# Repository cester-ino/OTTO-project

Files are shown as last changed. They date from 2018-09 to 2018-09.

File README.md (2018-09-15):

## OTTO-project
Hardware prototype for the OTTO Synthesizer 

Use Kicad to open the project

prototype rendering

The main features are (for now):

 - **50 key button matrix** 
 - **4 clickable color coded encoders**
 - **1W Audio amplifier** for the internal speaker
 - **Battery management and charging** circuit for the lipo/li-ion batteries and a led battery meter  
 - **Gpio breakout** to allow to position the Raspberry rotated 90 degrees to access the USB ports and to easely use both the LCD screen and the audio card.

prototype rendering

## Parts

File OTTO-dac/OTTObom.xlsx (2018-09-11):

Refs | Value | Footprint | Quantity | MFR | MPN | SPR | SPN | Column1
SW55 | ON_OFF_SWITCH | Button_Switch_THT:SK-12E12-G5 | 1 |  |  | lcsc | C136720
SW8;SW7;SW11;SW12;SW15;SW19;SW23;SW27;SW30;SW34;SW36;SW37;SW39;SW43;SW47;SW50;SW18;SW22;SW26;SW33;SW35;SW38;SW42;SW46;SW3;SW4;SW2;SW1;SW5;SW6;SW10;SW14;SW17;SW9;SW13;SW16;SW49;SW45;SW41;SW40;SW44;SW48;SW31;SW28;SW24;SW29;SW25;SW21;SW20;SW32 | SW_Push | Button_Switch_THT:Tactile_Switch_12x12x7.3_mm | 50 | - | - | lcsc | -
MK1 | Microphone | CMA-4544PF-W:CMA-4544PF-W | 1 | - | - | lcsc | C241681 (https://lcsc.com/product-detail/Others_INGHAi-GMI9750UP-2C44DB_C241681.html)
C22 | 0.01uF | Capacitor_SMD:C_0805_2012Metric | 1 | - | - | lcsc | C83170 (https://lcsc.com/product-detail/Multilayer-Ceramic-Capacitors-MLCC-SMD-SMT_10nF-103-10-50V_C83170.html)
C7;C11;C8;C9;C10;C13;C1;C6;C5;C21 | 0.1uF | Capacitor_SMD:C_0805_2012Metric | 10 | - | - | lcsc | C29926 (https://lcsc.com/product-detail/Multilayer-Ceramic-Capacitors-MLCC-SMD-SMT_100nF-104-5-50V_C29926.html) | V
C24 | 100pF | Capacitor_SMD:C_0805_2012Metric | 1 | - | - | lcsc | C107140 (https://lcsc.com/product-detail/Multilayer-Ceramic-Capacitors-MLCC-SMD-SMT_100pF-101-10-50V_C107140.html)
C12 | 10uF | Capacitor_SMD:C_0805_2012Metric | 1 | - | - | lcsc | C48181 (https://lcsc.com/product-detail/Multilayer-Ceramic-Capacitors-MLCC-SMD-SMT_10uF-106-20-25V_C48181.html)
C2;C23 | 1uF | Capacitor_SMD:C_0805_2012Metric | 2 | - | - | lcsc | C89378 (https://lcsc.com/product-detail/Multilayer-Ceramic-Capacitors-MLCC-SMD-SMT_1uF-105-20-25V_C89378.html)
C3;C4 | 22pF | Capacitor_SMD:C_0805_2012Metric | 2 | - | - | lcsc | C38143 (https://lcsc.com/product-detail/Multilayer-Ceramic-Capacitors-MLCC-SMD-SMT_22pF-220-5-50V_C38143.html)
C14 | 22uF | Capacitor_SMD:C_0805_2012Metric | 1 | - | - | lcsc | C89572 (https://lcsc.com/product-detail/Multilayer-Ceramic-Capacitors-MLCC-SMD-SMT_22uF-226-20-10V_C89572.html)
C19;C20 | 0.1uf | Capacitor_Tantalum_SMD:CP_EIA-2012-12_Kemet-R | 2 | - | - | lcsc | C154088
C18 | 1uf | Capacitor_Tantalum_SMD:CP_EIA-2012-12_Kemet-R | 1 | - | - | lcsc | C116269 (https://lcsc.com/product-detail/Tantalum-Capacitors_KEMET_T491A105K016AT_1uF-105-10-16V_C116269.html)
C16;C17 | 220uf | Capacitor_Tantalum_SMD:CP_EIA-2012-12_Kemet-R | 2 | - | - | lcsc | C7200
C15 | 22uF | Capacitor_Tantalum_SMD:CP_EIA-2012-12_Kemet-R | 1 | - | - | lcsc | C117031 (https://lcsc.com/product-detail/Tantalum-Capacitors_KEMET_T491B226M010AT_22uF-226-20-10V_C117031.html)
J10 | Conn_01x04_Male | Connector_JST:JST_SH_SM04B-SRSS-TB_1x04-1MP_P1.00mm_Horizontal | 1 | - | - | lcsc | C160404
J6 | Speaker | Connector_JST:JST_XH_B02B-XH-A_1x02_P2.50mm_Vertical | 1 | JST | XH-B02B | lcsc | C20079 (https://lcsc.com/product-detail/XH-Connectors_XH-2A-2P-pitch2-5mm-Straight-line_C20079.html)
J3 | battery | Connector_JST:JST_XH_B02B-XH-A_1x02_P2.50mm_Vertical | 1 | JST | XH-B02B | lcsc | C20079 (https://lcsc.com/product-detail/XH-Connectors_XH-2A-2P-pitch2-5mm-Straight-line_C20079.html)
J1 | USB | Connector_PinHeader_2.54mm:PinHeader_1x04_P2.54mm_Vertical | 1 | - | 1x04 pin header | lcsc | C124378 (https://lcsc.com/product-detail/Male-Header_Shenzhen-Cancome-Headers-Pins-1-4P-2-54mm-Straight-line_C124378.html)
J4 | audio | Connector_PinHeader_2.54mm:PinHeader_1x04_P2.54mm_Vertical | 1 | - | 1x04 pin header | lcsc | C124378 (https://lcsc.com/product-detail/Male-Header_Shenzhen-Cancome-Headers-Pins-1-4P-2-54mm-Straight-line_C124378.html)
J8 | gpio_exp1 | Connector_PinHeader_2.54mm:PinHeader_2x20_P2.54mm_Vertical | 1 | 2x20 long pin header | - | lcsc | C124383 (https://lcsc.com/product-detail/Male-Header_Shenzhen-Cancome-Headers-Pins-2-20P-2-54mm-Straight-line_C124383.html)
J7 | gpio_exp2 | Connector_PinHeader_2.54mm:PinHeader_2x20_P2.54mm_Vertical | 1 | 2x20 pin header | - | lcsc | C124383 (https://lcsc.com/product-detail/Male-Header_Shenzhen-Cancome-Headers-Pins-2-20P-2-54mm-Straight-line_C124383.html)
J2 | USB_B_Micro | Connector_USB:USB_Micro-B_Molex-105017-0001 | 1 | Molex | 105017-0001 | lcsc | C136000 (https://lcsc.com/product-detail/Micro-USB-Connectors_MOLEX_105017-0001_105017-0001_C136000.html)
Y1 | 16mhz | Crystal:Crystal_SMD_Abracon_ABM3-2Pin_5.0x3.2mm | 1 | - | ABM3-16.000MHZ-D2Y-T | lcsc | C112572 (https://lcsc.com/product-detail/SMD-Crystals_YSX530GA-16MHZ-20PF-10PPM-40-85_C112572.html)
D58 | SS34 | Diode_SMD:D_SMC | 1 | - | SS34 | lcsc | C13763 (https://lcsc.com/product-detail/Schottky-Barrier-Diodes-SBD_Jiangsu-Yutai-Elec-SS34_C13763.html)
D9;D8;D12;D13;D16;D20;D24;D28;D31;D35;D37;D38;D40;D44;D48;D51;D19;D23;D27;D34;D36;D39;D43;D47;D4;D5;D3;D2;D6;D7;D11;D15;D18;D10;D14;D17;D50;D46;D42;D41;D45;D49;D32;D29;D25;D30;D26;D22;D21;D33;D52;D53;D54;D55 | 1N4148 | Diode_SMD:D_SOD-123v | 54 | - | 1N4148W-E3-18 | lcsc | C129216 (https://lcsc.com/product-detail/Switching-Diode_1N4148W_C129216.html)
U7 | TJCTM24028-SPI | Display:TJCTM24028-SPI | 1 | - | - | lcsc | -
L1 | 22uH | Inductor_SMD:L_7.3x7.3_H4.5 | 1 | Epcos |  | lcsc | C181754
D1 | LED | LED_SMD:LED_0805_2012Metric | 1 | - | HSMW-C170-U0000 | lcsc | C34499 (https://lcsc.com/product-detail/Light-Emitting-Diodes-LED_white-0805_C34499.html)
D57 | LEDG | LED_SMD:LED_0805_2012Metric | 1 | - | HSMQ-C170-T0000 | lcsc | C74344 (https://lcsc.com/product-detail/Light-Emitting-Diodes-LED_0805_C74344.html)
D56 | LEDR | LED_SMD:LED_0805_2012Metric | 1 | - | HSMC-C170-T0000 | lcsc | C131250 (https://lcsc.com/product-detail/Infrared-IR-LEDs_Everlight-Elec-IR17-21C-TR8_C131250.html)
D59;D60;D61;D62;D63 | LED | LED_SMD:LED_0805_2012Metric | 5 | - | HSMW-C170-U0000 | lcsc | C34499 (https://lcsc.com/product-detail/Light-Emitting-Diodes-LED_white-0805_C34499.html)
IC2 | LM3914 | Package_LCC:PLCC-20 | 1 | - | LM3914VX/NOPB | lcsc | C9408 (https://lcsc.com/product-detail/LED-Drivers_TI_LM3914N-1-NOPB_LM3914N-1-NOPB_C9408.html)
U1 | ATMEGA32U4-AU | Package_QFP:TQFP-44-1EP_10x10mm_P0.8mm_EP4.5x4.5mm | 1 | - | ATMEGA32U4-AU | lcsc | 556-ATMEGA32U4-AU
IC1 | 74HC125 | Package_SO:SOIC-14_3.9x8.7mm_P1.27mm | 1 | - | SN74HC125DR | lcsc | 595-SN74HC125DR
U6 | LM4860 | Package_SO:SOIC-16_3.9x9.9mm_P1.27mm | 1 | - | LM4860MX/NOPB | lcsc | -
U2 | MCP602 | Package_SO:SOIC-8_3.9x4.9mm_P1.27mm | 1 | - | MCP6022T-I/SN | lcsc | -
U3 | TP4056 | Package_SO:Texas_HTSOP-8-1EP_3.9x4.9mm_P1.27mm_EP2.95x4.9mm_Mask2.4x3.1mm_ThermalVias | 1 | - | TP4056 SOP-8 | lcsc | C16581 (https://lcsc.com/product-detail/PMIC-Battery-Management_TP4056_C16581.html)
U4 | FS312F-G | Package_TO_SOT_SMD:SOT-23-6 | 1 | - | FS312F-G SOT-23 | lcsc | C82736 (https://lcsc.com/product-detail/Battery-Protection-ICs_FS312F-G_C82736.html)
U5 | MT3608 | Package_TO_SOT_SMD:SOT-23-6 | 1 | - | MT3608 SOT-23 | lcsc | C84817 (https://lcsc.com/product-detail/DC-DC-Converters_MT3608_C84817.html)
M1 | FS8205 | Package_TO_SOT_SMD:SOT-23-6_Handsoldering | 1 | - | FS8205 SOT-23 | lcsc | C94488 (https://lcsc.com/product-detail/MOSFET_RU8205C6_C94488.html)
U8 | MAX4466 | Package_TO_SOT_SMD:SOT-353_SC-70-5 | 1 | - | - | lcsc | -
Q1 | 2N7000 | Package_TO_SOT_THT:TO-92_Inline | 1 | - | - | lcsc | C232838
RV1 | 10K | Potentiometer_SMD:Potentiometer_Vishay_TS53YJ_Vertical | 1 | - | TS53YJ103MR10 | lcsc | C118956 (https://lcsc.com/product-detail/Precision-Potentiometer_10KR_C118956.html)
R15;R13 | 1.5K | Resistor_SMD:R_0805_2012Metric | 2 | - | - | lcsc | C114737 (https://lcsc.com/product-detail/Chip-Resistor-Surface-Mount_1-5KR-152-5_C114737.html) | V
R23;R31;R32;R35;R41 | 100K | Resistor_SMD:R_0805_2012Metric | 5 | - | - | lcsc | C96346 (https://lcsc.com/product-detail/Chip-Resistor-Surface-Mount_100KR-1003-1_C96346.html) | V
R1;R8;R3;R12;R7;R9;R4;R10;R5;R11;R6;R33;R34 | 10K | Resistor_SMD:R_0805_2012Metric | 13 | - | - | lcsc | C101926 (https://lcsc.com/product-detail/Chip-Resistor-Surface-Mount_10KR-103-5_C101926.html) | V
R18 | 15K | Resistor_SMD:R_0805_2012Metric | 1 | - | - | lcsc | C114559 (https://lcsc.com/product-detail/Chip-Resistor-Surface-Mount_15KR-1502-1_C114559.html) | V
R17;R19;R21;R20;R26;R30;R29;R28;R40;R38;R36 | 1K | Resistor_SMD:R_0805_2012Metric | 11 | - | - | lcsc | C100046 (https://lcsc.com/product-detail/Chip-Resistor-Surface-Mount_1KR-102-5_C100046.html) | V
R39;R37 | 1M | Resistor_SMD:R_0805_2012Metric | 2 | - | - | lcsc | C107700 (https://lcsc.com/product-detail/Chip-Resistor-Surface-Mount_1MR-1004-1_C107700.html) | V
R24 | 2.7k | Resistor_SMD:R_0805_2012Metric | 1 | - | - | lcsc | C137454 | V
R22 | 2k | Resistor_SMD:R_0805_2012Metric | 1 | - | - | lcsc | C114748 (https://lcsc.com/product-detail/Chip-Resistor-Surface-Mount_2KR-202-5_C114748.html) | V
R2 | 330K | Resistor_SMD:R_0805_2012Metric | 1 | - | - | lcsc | C114528 (https://lcsc.com/product-detail/Chip-Resistor-Surface-Mount_330KR-3303-1_C114528.html) | V
R27 | 4.7K | Resistor_SMD:R_0805_2012Metric | 1 | - | - | lcsc | C60816 (https://lcsc.com/product-detail/Chip-Resistor-Surface-Mount_4-7K-4701-1_C60816.html) | V
R14 | 470K | Resistor_SMD:R_0805_2012Metric | 1 | - | - | lcsc | C104346 (https://lcsc.com/product-detail/Chip-Resistor-Surface-Mount_470KR-4703-1_C104346.html) | V
R25 | 7.5K | Resistor_SMD:R_0805_2012Metric | 1 | - | - | lcsc | C114547 (https://lcsc.com/product-detail/Chip-Resistor-Surface-Mount_7-5KR-7501-1_C114547.html) | V
R16 | 820K | Resistor_SMD:R_0805_2012Metric | 1 | - | - | lcsc | C141700 | V
SW51;SW52;SW53;SW54 | Rotary_Encoder_Switch | Rotary_Encoder:RotaryEncoder_Alps_EC12E-Switch_Vertical_H20mm_CircularMountingHoles | 4 | - |  | lcsc | C202365
J5 | SJ1-42536-SMT | SJ1:CUI_SJ1-42536-SMT | 1 | Cui | SJ1-42536-SMT | lcsc | C128992

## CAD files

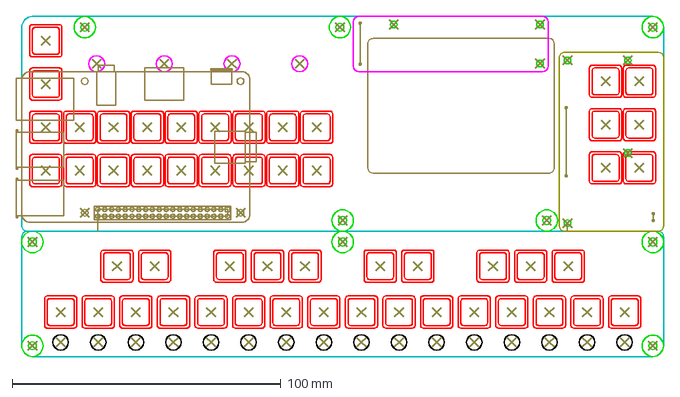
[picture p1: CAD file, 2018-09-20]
OTTO_align.dxf
241.0 x 126.6 mm

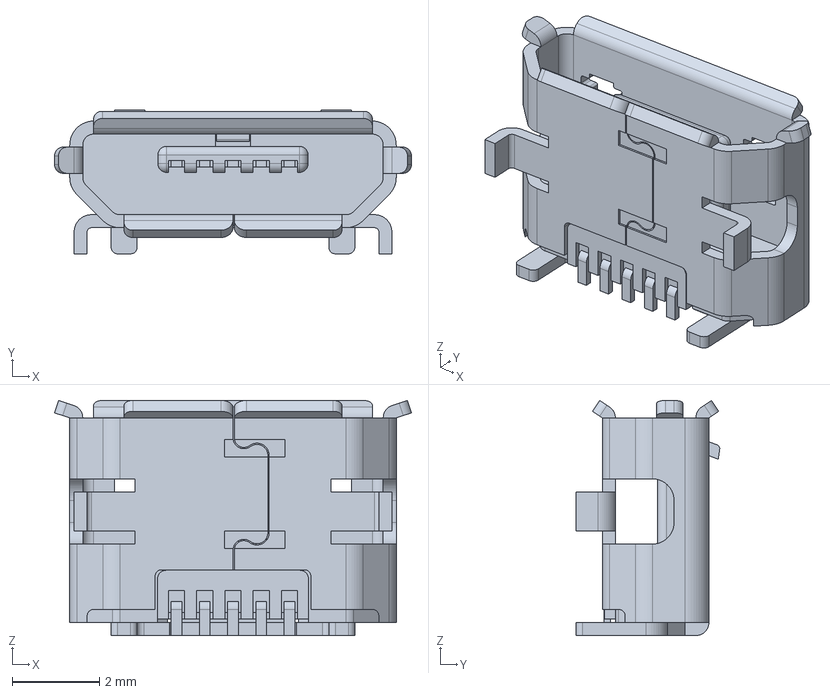
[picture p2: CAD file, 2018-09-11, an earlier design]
OTTO-old/3D Shapes/1050170001.stp
8.20 x 3.30 x 5.40 mm

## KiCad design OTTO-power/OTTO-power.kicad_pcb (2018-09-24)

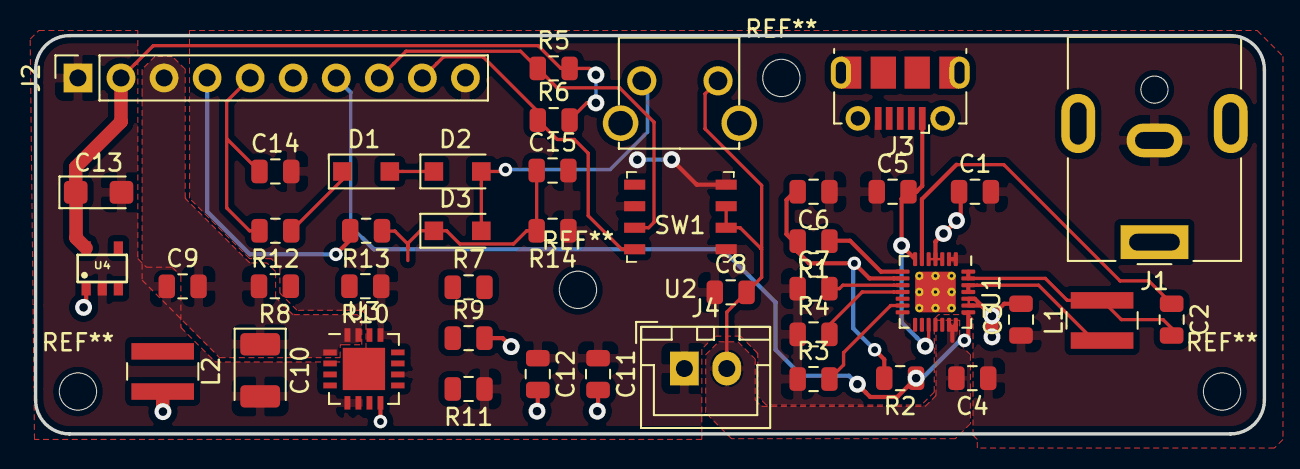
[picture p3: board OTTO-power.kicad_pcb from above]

Board: 2 copper layers, 72.5 x 23.5 mm, 43 parts (0 on the bottom side), 27 nets.

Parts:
C1, C6, C9: 2.2uf; C_0805_2012Metric
C2: 1uf; C_0805_2012Metric
C3, C4, C11: 10uf; C_0805_2012Metric
C5: 4.7uf; C_0805_2012Metric
C7: 0.15uf; C_0805_2012Metric
C8, C12: 0.1uf; C_0805_2012Metric
C10: 100uf; CP_EIA-3528-21_Kemet-B
C13: 10uf; CP_EIA-3216-18_Kemet-A
C14, C15: 0.1uF; C_0805_2012Metric
D1, D2, D3: IN4001; D_SOD-123F
J1: Barrel_Jack; BarrelJack_CUI_PJ-063AH_Horizontal
J2: Conn_01x10; PinSocket_1x10_P2.54mm_Vertical
J3: USB_B_Micro; USB_Micro-B_Molex-105017-0001
J4: battery; JST_XH_B02B-XH-A_1x02_P2.50mm_Vertical
L1: 3.3uH; L_Wuerth_MAPI-4020
L2: 6.8uH; L_Wuerth_MAPI-4020
R1, R2, R5, R6: 100K; R_0805_2012Metric
R3: 1.2K; R_0805_2012Metric
R4: 3K; R_0805_2012Metric
R7, R10: 200K; R_0805_2012Metric
R8, R9: 1.87M; R_0805_2012Metric
R11: 340K; R_0805_2012Metric
R12, R13, R14: 10K; R_0805_2012Metric
SW1: SW_Push; SKHHLVA010
U1: MAX8903A; QFN-28-1EP_4x4mm_P0.4mm_EP2.4x2.4mm_ThermalVias
U2: MAX17048; TDFN-8-1EP
U3: TPS61090; QFN-16-1EP_4x4mm_P0.65mm_EP2.5x2.5mm
U4: XC6210; SOT25

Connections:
3V3: C13.1, J2.2, R5.2, R6.2, U4.5
5V: C9.2, C10.1, J2.3, R8.2, U3.1, U3.15, U3.16
BATT+: C4.2, C8.2, J4.2, R7.2, SW1.1, U1.20, U1.21, U2.2, U2.3
CHG_OUT: J2.7, R2.1, U1.22
DC: C1.1, J1.1, U1.3, U1.4, U1.5
DOK_OUT: J2.6, R1.1, U1.8
EN_PI: C15.1, D3.1, R7.1, R13.1, R14.2, U3.11, U4.3
GNDA: C1.2, C3.1, C4.1, C5.1, C6.1, C7.1, C8.1, C9.1, C10.2, C11.1, C12.1, C13.2, C14.2, C15.2, J1.2, J2.1, J2.10, J3.5, J4.1, R3.1, R4.1, R10.1, R11.1, R14.1, U1.1, U1.2, U1.12, U1.14, U1.15, U1.16, U2.1, U2.4, U2.6, U3.5, U3.6, U3.7, U3.10, U3.13, U3.17, U4.2
unnamed: C2.1, U1.6
unnamed: C2.2, L1.2, U1.27, U1.28
unnamed: C7.2, U1.10
unnamed: D1.1, R12.1
unnamed: D1.2, D2.1
unnamed: D2.2, D3.2, SW1.2
unnamed: L1.1, U1.25, U1.26
unnamed: L2.1, U3.3, U3.4
unnamed: R3.2, U1.13
unnamed: R4.2, U1.11
unnamed: R8.1, R10.2, U3.14
unnamed: R9.1, R11.2, U3.9
OUT_PIN: J2.4, R13.2
SCL: J2.8, R5.1, U2.7
SDA: J2.9, R6.1, U2.8
SENSE_PIN: C14.1, J2.5, R12.2
SYS: C3.2, C11.2, C12.2, L2.2, R9.2, U1.23, U1.24, U3.8, U4.1
USB: C5.2, J3.1, U1.7, U1.17
VL: C6.2, R1.2, R2.2, U1.9

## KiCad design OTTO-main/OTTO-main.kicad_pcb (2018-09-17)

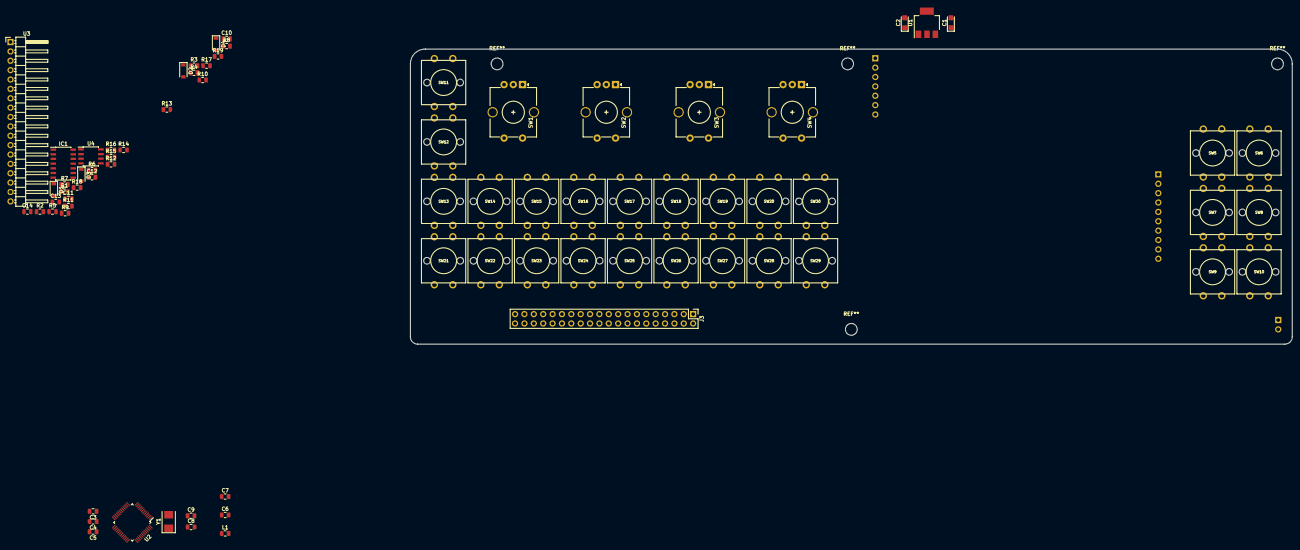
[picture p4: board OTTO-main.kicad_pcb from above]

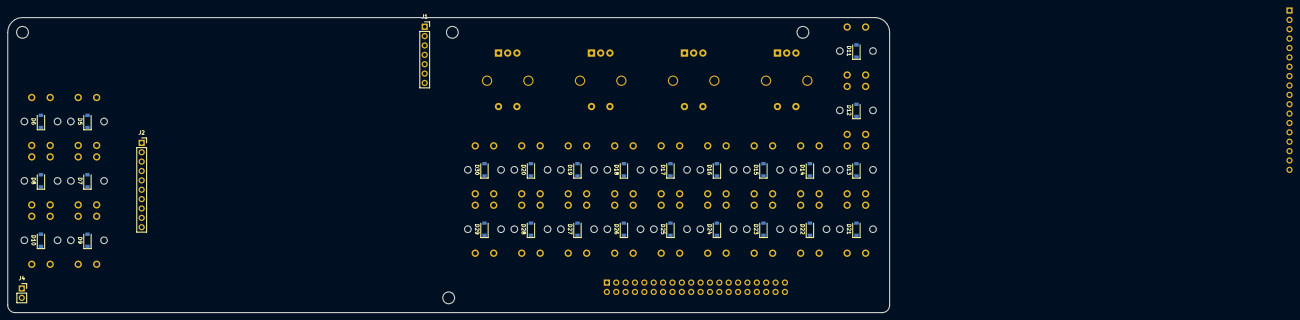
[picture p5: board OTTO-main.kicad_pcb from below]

Board: 2 copper layers, 239.0 x 80.0 mm, 104 parts (29 on the bottom side), 81 nets, no tracks yet.

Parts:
C1: 10uf; CP_EIA-3216-18_Kemet-A
C2: 22uf; CP_EIA-3216-18_Kemet-A
C3, C4, C5, C6: 1uf; C_0805_2012Metric
C7: 10nf; C_0805_2012Metric
C8, C9: 22pf; C_0805_2012Metric
C10, C11, C12, C13, C14: 0.1uF; C_0805_2012Metric
D1, D2, D3, D4: 1N4148; D_SOD-123v
D5, D6, D7, D8, D9, D10, D11, D12, D13, D14, D15, D16, D17, D18, D19, D20, D21, D22, D23, D24, D25, D26, D27, D28, D29, D30: D_ALT; D_SOD-123
IC1: 74HC125; SOIC-14_3.9x8.7mm_P1.27mm
J1: POWER_BOARD; PinSocket_1x07_P2.54mm_Vertical
J2: AUDIO_BOARD; PinSocket_1x10_P2.54mm_Vertical
J3: Raspberry_Pi_2_3; PinHeader_2x20_P2.54mm_Vertical
J4: MICROPHONE; PinSocket_1x02_P2.54mm_Vertical
L1: 30ohm; C_0805_2012Metric
R1, R2: 4.7K; R_0805_2012Metric
R3, R4, R5, R6, R7, R8, R9, R10, R11, R12: 10K; R_0805_2012Metric
R13, R15: 1.5K; R_0805_2012Metric
R14: 470K; R_0805_2012Metric
R16: 820K; R_0805_2012Metric
R17, R19: 1K; R_0805_2012Metric
R18: 15K; R_0805_2012Metric
SW1, SW2, SW3, SW4: Rotary_Encoder_Switch; RotaryEncoder_Alps_EC12E-Switch_Vertical_H20mm_CircularMoun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
SW5, SW6, SW7, SW8, SW9, SW10, SW11, SW12, SW13, SW14, SW15, SW16, SW17, SW18, SW19, SW20, SW21, SW22, SW23, SW24, SW25, SW26, SW27, SW28, SW29, SW30: SW_SPST; Tactile_Switch_12x12x7.3_mm
U1: AMS1117-3.3; SOT-223-3_TabPin2
U2: STM32F103CBTx; LQFP-48_7x7mm_P0.5mm
U3: ILI9341; PinHeader_1x18_P2.54mm_Horizontal
U4: MCP602; SOIC-8_3.9x4.9mm_P1.27mm
Y1: 8mhz; Crystal_SMD_5032-2Pin_5.0x3.2mm

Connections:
5V: J1.2, J2.8
+3V3: C2.1, C3.1, C4.1, C5.1, L1.2, U1.2, U2.24, U2.36, U2.48
+5V: C1.1, IC1.2, IC1.5, IC1.9, IC1.12, IC1.14, R1.2, R2.1, R3.2, R4.2, R5.2, R6.2, R7.2, R18.2, U1.3
A_PIN: IC1.10, R13.2, R14.1, U4.2
BCLK: J2.3, J3.12
CE0: J3.24, U3.5
COL1: D1.1, D11.1, D21.1
COL2: D2.1, D12.1, D22.1
COL3: D3.1, D13.1, D23.1
COL4: D4.1, D14.1, D24.1
COL5: D5.1, D15.1, D25.1
COL6: D6.1, D16.1, D26.1
COL7: D7.1, D17.1, D27.1
COL8: D8.1, D18.1, D28.1
COL9: D9.1, D19.1, D29.1
COL10: D10.1, D20.1, D30.1
D_PIN: C10.1, R8.1
GNDREF: C1.2, C2.2, C3.2, C4.2, C5.2, C6.2, C7.2, C8.2, C9.2, C10.2, C11.2, C12.2, C13.2, C14.2, IC1.7, J2.1, J2.9, J3.6, J3.9, J3.14, J3.20, J3.25, J3.30, J3.34, J3.39, R13.1, R17.2, R19.1, SW1.C, SW2.C, SW3.C, SW4.C, U1.1, U2.44, U3.1, U3.8, U3.11, U3.12, U3.13, U3.14
I2S_RX: J2.4, J3.40
I2S_TX: J2.5, J3.38
INT_PIN: R19.2, U4.1
LED_G: J1.6, J3.18
LED_R: J1.7, J3.22
LR_CLK: J2.2, J3.35
MISO_0: J3.21, U3.7
MOSI_0: J3.19, U3.6
unnamed: C6.1, C7.1, L1.1, U2.9
unnamed: C11.1, IC1.8, R9.1
unnamed: C12.1, IC1.11, R10.1
unnamed: C13.1, IC1.3, R11.1
unnamed: C14.1, IC1.6, R12.1
unnamed: D1.2, SW1.S2
unnamed: D2.2, SW2.S2
unnamed: D3.2, SW3.S2
unnamed: D4.2, SW4.S2
unnamed: D5.2, SW5.2
unnamed: D6.2, SW6.2
unnamed: D7.2, SW7.2
unnamed: D8.2, SW8.2
unnamed: D9.2, SW9.2
unnamed: D10.2, SW10.2
unnamed: D11.2, SW11.2
unnamed: D12.2, SW12.2
unnamed: D13.2, SW13.2
unnamed: D14.2, SW14.2
unnamed: D15.2, SW15.2
unnamed: D16.2, SW16.2
unnamed: D17.2, SW17.2
unnamed: D18.2, SW18.2
unnamed: D19.2, SW19.2
unnamed: D20.2, SW20.2
unnamed: D21.2, SW21.2
unnamed: D22.2, SW22.2
unnamed: D23.2, SW23.2
unnamed: D24.2, SW24.2
unnamed: D25.2, SW25.2
unnamed: D26.2, SW26.2
unnamed: D27.2, SW27.2
unnamed: D28.2, SW28.2
unnamed: D29.2, SW29.2
unnamed: D30.2, SW30.2
unnamed: IC1.1, R15.2, R16.2
unnamed: IC1.4, R15.1
unnamed: IC1.13, R14.2, R16.1
unnamed: R3.1, R8.2, SW1.A, SW2.A, SW3.A, SW4.A
unnamed: R4.1, R9.2, SW1.B
unnamed: R5.1, R10.2, SW2.B
unnamed: R6.1, R11.2, SW3.B
unnamed: R7.1, R12.2, SW4.B
unnamed: R17.1, R18.1, U4.3
OSC_IN: C8.1, U2.5, Y1.1
OSC_OUT: C9.1, U2.6, Y1.2
OUT_PIN: J1.4, J3.15
ROW1: SW1.S1, SW2.S1, SW3.S1, SW4.S1, SW5.1, SW6.1, SW7.1, SW8.1, SW9.1, SW10.1
ROW2: SW11.1, SW12.1, SW13.1, SW14.1, SW15.1, SW16.1, SW17.1, SW18.1, SW19.1, SW20.1
ROW3: SW21.1, SW22.1, SW23.1, SW24.1, SW25.1, SW26.1, SW27.1, SW28.1, SW29.1, SW30.1
SCL: J2.6, J2.7, J3.3, J3.5, R1.1, R2.2, U2.42, U2.43
SCLK_0: J3.23, U3.3
SENSE_PIN: J1.5, J3.16
UART_RXD: J3.10, U2.30
UART_TXD: J3.8, U2.31

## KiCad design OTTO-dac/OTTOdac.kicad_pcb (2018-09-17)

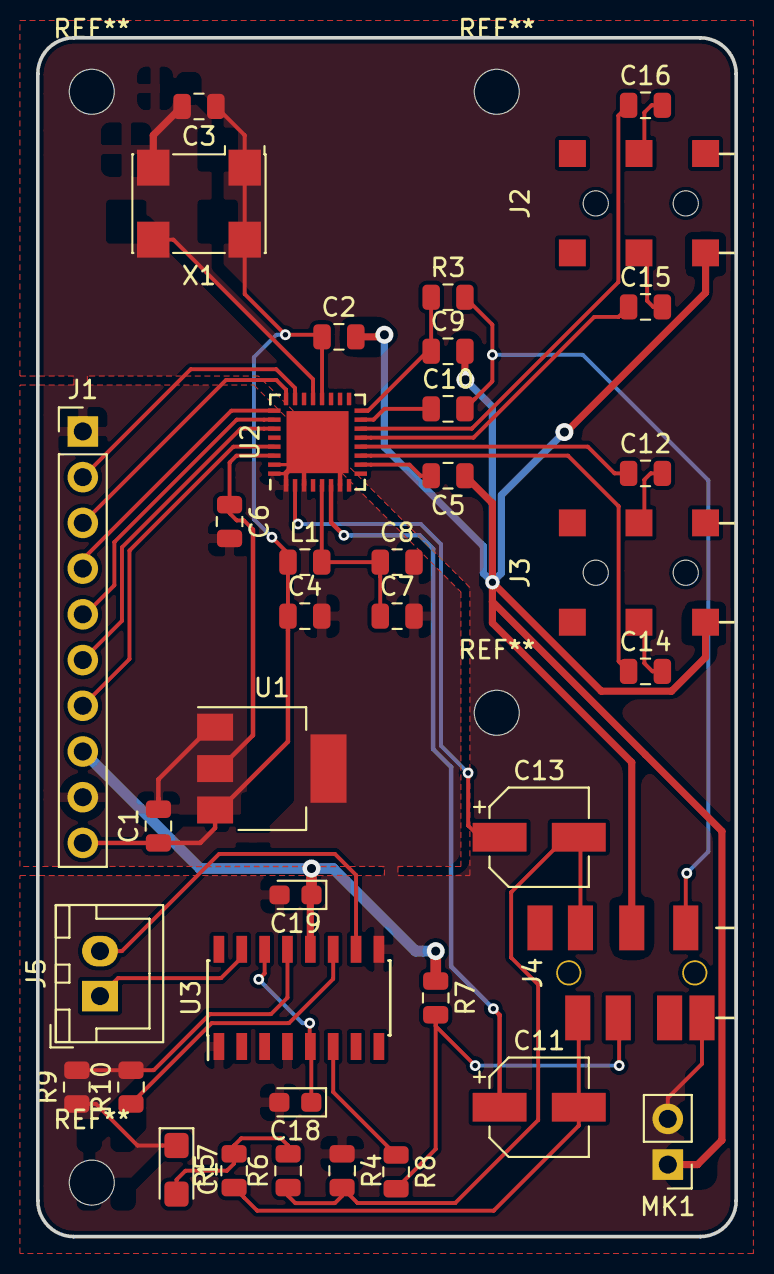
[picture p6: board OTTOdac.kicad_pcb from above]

Board: 2 copper layers, 38.8 x 66.6 mm, 38 parts (0 on the bottom side), 39 nets.

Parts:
C1, C6, C7, C9, C12, C14, C15, C16: 2.2uf; C_0805_2012Metric
C2, C3, C4, C5, C8, C10: 0.1uf; C_0805_2012Metric
C11, C13: 220uf; CP_Elec_5x4.5
C17: 1uf; CP_EIA-3216-18_Kemet-A
C18, C19: 0.1uf; CP_EIA-2012-12_Kemet-R
J1: Conn_01x10; PinHeader_1x10_P2.54mm_Vertical
J2: Audio_IN; PJ-237-6A
J3: Audio_OUT; PJ-237-6A
J4: SJ1-42536-SMT; PJ-393-7A
J5: Speaker; JST_XH_B02B-XH-A_1x02_P2.50mm_Vertical
L1: 600; Fuse_0805_2012Metric
MK1: Microphone; PinHeader_1x02_P2.54mm_Vertical
R3: 2.2K; R_0805_2012Metric
R4, R5, R6: 1K; R_0805_2012Metric
R7, R8: 100K; R_0805_2012Metric
R9, R10: 10K; R_0805_2012Metric
U1: AMS1117-3.3; SOT-223-3_TabPin2
U2: SGTL5000; QFN-32-NXP-SGTL5000
U3: LM4860; SOIC-16_3.9x9.9mm_P1.27mm
X1: XO32; Oscillator_SMD_Abracon_ASV-4Pin_7.0x5.1mm

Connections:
+3V3: C1.1, C2.1, C3.1, C4.1, J1.10, L1.1, U1.3, U2.20, X1.1, X1.4
+5V: C19.1, J1.8, R7.1, U3.12
GNDREF: C1.2, C2.2, C3.2, C4.2, C5.1, C6.2, C7.2, C8.2, C9.2, C18.2, C19.2, J1.1, J1.9, J2.1, J3.1, J4.4, MK1.1, R4.1, U1.1, U2.1, U2.3, U2.7, U2.31, U2.32, U2.33, U3.1, U3.4, U3.9, X1.2
HPL: C11.2, J4.2, R5.1
HPR: C13.2, J4.3, R4.2, R6.1
MIC: C10.2, J4.1, R3.2
unnamed: C5.2, U2.10
unnamed: C6.1, U1.2, U2.30
unnamed: C7.1, C8.1, L1.2, U2.5
unnamed: C9.1, R3.1, U2.16
unnamed: C10.1, U2.15
unnamed: C11.1, U2.6
unnamed: C12.1, U2.12
unnamed: C12.2, J3.2
unnamed: C13.1, U2.2
unnamed: C14.1, U2.11
unnamed: C14.2, J3.3
unnamed: C15.1, U2.13
unnamed: C15.2, J2.3
unnamed: C16.1, U2.14
unnamed: C16.2, J2.2
unnamed: C17.1, R9.1
unnamed: C17.2, R5.2, R6.2
unnamed: C18.1, U3.5, U3.14
unnamed: J4.6, R7.2, R8.2
unnamed: J4.8, MK1.2
unnamed: J5.1, U3.15
unnamed: J5.2, U3.10
unnamed: R8.1, U3.6
unnamed: R10.1, U3.11
unnamed: R9.2, R10.2, U3.13
unnamed: U2.21, X1.3
unnamed: U3.2, U3.3
PIN3: J1.6, U2.27
PIN5: J1.7, U2.29
PIN12: J1.3, U2.24
PIN35: J1.2, U2.23
PIN38: J1.5, U2.26
PIN40: J1.4, U2.25

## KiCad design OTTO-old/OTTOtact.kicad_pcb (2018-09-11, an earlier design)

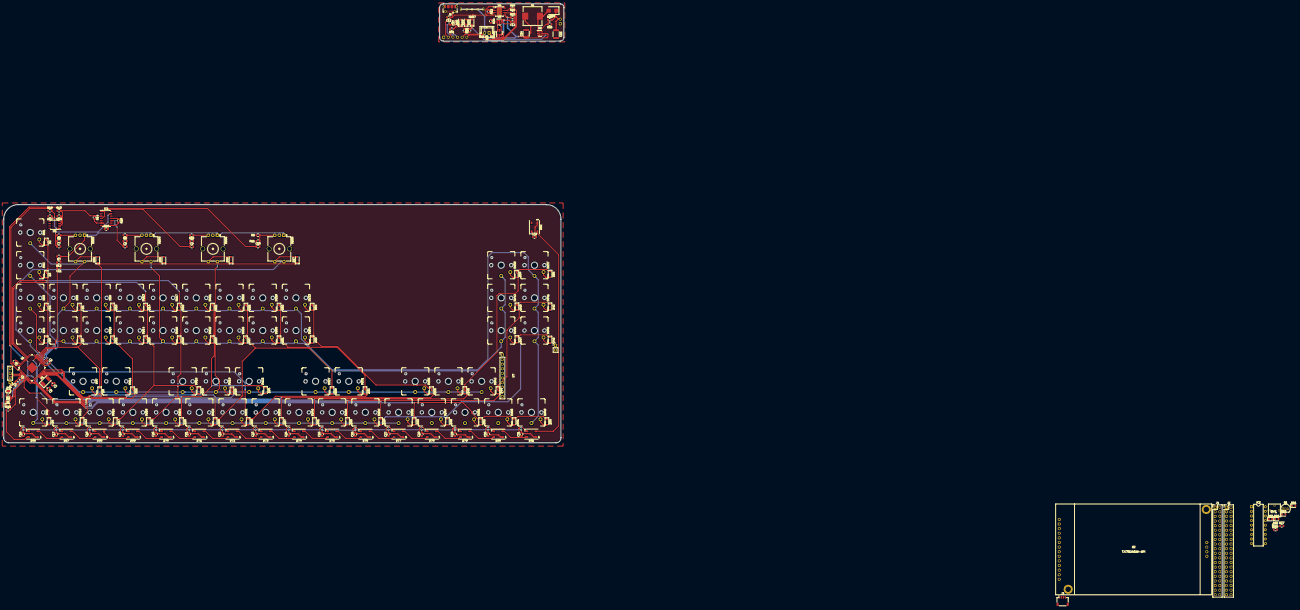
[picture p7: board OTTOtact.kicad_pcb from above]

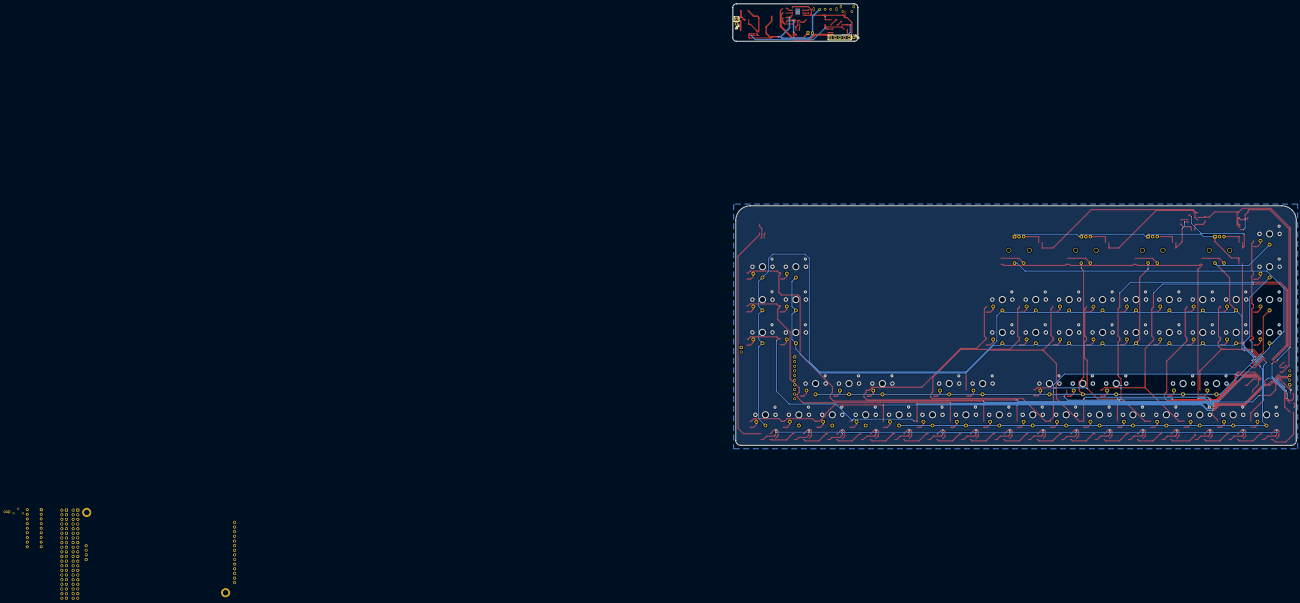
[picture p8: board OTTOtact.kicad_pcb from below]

Board: 2 copper layers, 307.0 x 131.2 mm, 229 parts (2 on the bottom side), 184 nets.

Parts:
C1, C5, C6, C7, C8, C9, C10, C11, C13, C33, C34: 0.1uF; C_0805_2012Metric
C2: 1uF; C_0805_2012Metric
C3, C4: 22pF; C_0805_2012Metric
C12: 10uF; C_0805_2012Metric
C14, C15: 22uF; C_1812_4532Metric
C16, C17, C18, C19, C20, C21, C22, C23, C24, C25, C26, C27, C28, C29, C30, C31, C32: 0.1uf; C_0805_2012Metric
D1: LED; LED_0805_2012Metric
D2, D3, D4, D5, D6, D7, D8, D9, D10, D11, D12, D13, D14, D15, D16, D17, D18, D19, D20, D21, D22, D23, D24, D25, D26, D27, D28, D29, D30, D31, D32, D33, D34, D35, D36, D37, D38, D39, D40, D41, D42, D43, D44, D45, D46, D47, D48, D49, D50, D51, D52, D53, D54, D55, D56, D57: 1N4148; D_SOD-123v
D60: SS34; D_SMB
D61, D62, D63, D64, D65: LED_Small; LED_0805_2012Metric
D66, D67, D68, D69, D70, D71, D72, D73, D74, D75, D76, D77, D78, D79, D80, D81, D82: WS2812B; LED_WS2812B_PLCC4_5.0x5.0mm_P3.2mm
D83, D84, D85: IN4001; D_SOD-123F
IC1: 74HC125; SOIC-14_3.9x8.7mm_P1.27mm
IC2: LM3914; DIP-18_W7.62mm
J1: USB; PinHeader_1x04_P2.54mm_Vertical
J2: gpio_exp2; PinHeader_2x20_P2.54mm_Vertical
J3: Conn_01x04_Male; JST_SH_SM04B-SRSS-TB_1x04-1MP_P1.00mm_Horizontal
J4: gpio_exp1; PinHeader_2x20_P2.54mm_Vertical
J5: USB_B_Micro; USB_Micro-B_Molex-105017-0001
J6: battery; JST_XH_B02B-XH-A_1x02_P2.50mm_Vertical
J7: Conn_01x06; PinHeader_1x06_P2.54mm_Vertical
J8: Conn_01x02; PinHeader_1x02_P2.54mm_Vertical
JP1: SolderJumper_2_Open; SolderJumper-2_P1.3mm_Open_RoundedPad1.0x1.5mm
L1: 22uH; L_Wuerth_HCI-1040
M1: FS8205; SOT-23-6_Handsoldering
Q1: 2N7000; TO-92_Inline
R1, R3, R4, R5, R6, R7, R8, R9, R10, R11, R12, R30, R31, R32: 10K; R_0805_2012Metric
R2: 330K; R_0805_2012Metric
R13, R15: 1.5K; R_0805_2012Metric
R14: 470K; R_0805_2012Metric
R16: 820K; R_0805_2012Metric
R17, R19, R20, R21, R26: 1K; R_0805_2012Metric
R18: 15K; R_0805_2012Metric
R22: 2k; R_0805_2012Metric
R23, R28: 100K; R_0805_2012Metric
R24: 2.7k; R_0805_2012Metric
R25: 7.5K; R_0805_2012Metric
R27: 4.7K; R_0805_2012Metric
R29: 330; R_0805_2012Metric
RV1: 10K; 3362P_1
SW1, SW2, SW3, SW4, SW5, SW6, SW7, SW8, SW9, SW10, SW11, SW12, SW13, SW14, SW15, SW16, SW17, SW18, SW19, SW20, SW21, SW22, SW23, SW24, SW25, SW26, SW27, SW28, SW29, SW30, SW31, SW32, SW33, SW34, SW35, SW36, SW37, SW38, SW39, SW40, SW41, SW42, SW43, SW44, SW45, SW46, SW47, SW48, SW49, SW50, SW51, SW52: SW_Push; kaihl-low-profile-switch-noled
SW53, SW54, SW55, SW56: Rotary_Encoder_Switch; RotaryEncoder_Alps_EC12E-Switch_Vertical_H20mm_CircularMoun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
SW57: ON_OFF_SWITCH; SK-12E12-G5
U1: ATMEGA32U4-AU; TQFP-44-1EP_10x10mm_P0.8mm_EP4.5x4.5mm
U2: TJCTM24028-SPI
U3: MCP602; SOIC-8_3.9x4.9mm_P1.27mm
U4: TP4056; Texas_HTSOP-8-1EP_3.9x4.9mm_P1.27mm_EP2.95x4.9mm_Mask2.4x3.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
U5: FS312F-G; SOT-23-6
U6: MT3608; SOT-23-6
U7: OTTO-dac; OTTO_DACv0.1
Y1: 16mhz; Crystal_SMD_Abracon_ABM3-2Pin_5.0x3.2mm

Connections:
5V: C15.1, D60.1, J8.2, R25.2
36: J2.36, J4.36, Q1.2, R28.1
+5V: C1.2, C5.1, C6.2, C16.2, C17.2, C18.2, C19.2, C20.2, C21.2, C22.2, C23.2, C24.2, C25.2, C26.2, C27.2, C28.2, C29.2, C30.2, C31.2, C32.2, D1.2, D66.1, D67.1, D68.1, D69.1, D70.1, D71.1, D72.1, D73.1, D74.1, D75.1, D76.1, D77.1, D78.1, D79.1, D80.1, D81.1, D82.1, IC1.2, IC1.5, IC1.7, IC1.9, IC1.12, J2.2, J4.2, R1.1, R3.2, R4.2, R5.2, R6.2, R7.2, R18.2, U1.2, U1.7, U1.14, U1.24, U1.34, U1.44, U7.8
-BATT: C13.2, J6.1, M1.3, U5.6
/gpio/1: J2.1, J3.2, J4.1, U2.1, U7.10
/gpio/3: J2.3, J3.3, J4.3, U7.6
/gpio/4: J2.4, J4.4
/gpio/5: J2.5, J3.4, J4.5, U7.7
/gpio/7: J2.7, J4.7
/gpio/8: J2.8, J4.8
/gpio/9: J2.9, J4.9
/gpio/11: J2.11, J4.11
/gpio/12: J2.12, J4.12, U2.8, U7.3
/gpio/13: J2.13, J4.13
/gpio/14: J2.14, J4.14
/gpio/15: J2.15, J4.15
/gpio/16: J2.16, J4.16
/gpio/17: J2.17, J4.17
/gpio/18: J2.18, J4.18, U2.5
/gpio/19: J2.19, J4.19, U2.6
/gpio/20: J2.20, J4.20
/gpio/21: J2.21, J4.21, U2.9
/gpio/22: J2.22, J4.22, U2.4
/gpio/23: J2.23, J4.23, U2.7
/gpio/24: J2.24, J4.24, U2.3
/gpio/25: J2.25, J4.25
/gpio/26: J2.26, J4.26
/gpio/27: J2.27, J4.27
/gpio/28: J2.28, J4.28
/gpio/29: J2.29, J4.29
/gpio/30: J2.30, J4.30
/gpio/31: J2.31, J4.31
/gpio/32: J2.32, J4.32
/gpio/33: J2.33, J4.33
/gpio/34: J2.34, J4.34
/gpio/35: J2.35, J4.35, U7.2
/gpio/37: J2.37, J4.37
/gpio/38: J2.38, J4.38, U7.5
/gpio/39: J2.39, J4.39
/gpio/40: J2.40, J4.40, U7.4
BATT: C14.1, D61.2, D62.2, D63.2, D64.2, D65.2, IC2.3, IC2.9, J6.2, L1.1, R23.1, R27.2, SW57.3, U4.5, U6.5
COL1: D2.1, D3.1, D4.1, D5.1, U1.29
COL2: D6.1, D7.1, D8.1, D9.1, U1.31
COL3: D10.1, D11.1, D12.1, D13.1, U1.32
COL4: D14.1, D15.1, D16.1, D17.1, U1.36
COL5: D18.1, D19.1, D20.1, D21.1, U1.37
COL6: D22.1, D23.1, D24.1, D25.1, U1.22
COL7: D26.1, D27.1, D28.1, D29.1, U1.21
COL8: D30.1, D31.1, D32.1, D33.1, U1.20
COL9: D34.1, D35.1, D36.1, D37.1, U1.19
COL10: D38.1, D39.1, D40.1, D41.1, U1.18
COL11: D42.1, D43.1, D44.1, D45.1, U1.12
COL12: D46.1, D47.1, D48.1, D49.1, U1.11
COL13: D50.1, D51.1, D52.1, D53.1, U1.10
COL14: D54.1, D55.1, D56.1, D57.1, U1.9
D+: J1.2, U1.4
D-: J1.3, U1.3
EN: C34.1, D85.1, R31.1, R32.2, U6.4
GNDREF: C1.1, C2.2, C3.2, C4.2, C5.2, C6.1, C7.2, C8.2, C9.2, C10.2, C11.2, C12.2, C14.2, C15.2, C16.1, C17.1, C18.1, C19.1, C20.1, C21.1, C22.1, C23.1, C24.1, C25.1, C26.1, C27.1, C28.1, C29.1, C30.1, C31.1, C32.1, C33.1, C34.2, D66.3, D67.3, D68.3, D69.3, D70.3, D71.3, D72.3, D73.3, D74.3, D75.3, D76.3, D77.3, D78.3, D79.3, D80.3, D81.3, D82.3, IC1.14, J1.1, J2.6, J3.1, J4.6, J5.5, J5.6, J7.1, J8.1, JP1.2, M1.1, Q1.1, R13.1, R17.2, R19.1, R22.2, R24.2, R26.1, R28.2, R32.1, SW53.C, SW54.C, SW55.C, SW56.C, U1.5, U1.15, U1.23, U1.33, U1.35, U1.43, U1.45, U2.2, U4.1, U4.3, U4.9, U6.2, U7.1, U7.9
LED: R29.2, U1.8
LED_G: J7.5, R21.2
LED_POW: C12.1, J5.1, J7.2, U4.4, U4.8
LED_R: J7.6, R20.2
unnamed: C2.1, U1.17, Y1.2
unnamed: C3.1, U1.16, Y1.1
unnamed: C4.1, U1.6
unnamed: C7.1, IC1.13, R8.1
unnamed: C8.1, IC1.10, R9.1
unnamed: C9.1, IC1.4, R10.1
unnamed: C10.1, IC1.1, R11.1
unnamed: C13.1, R23.2, U5.5
unnamed: D1.1, R2.1
unnamed: D2.2, SW1.2
unnamed: D3.2, SW2.2
unnamed: D4.2, SW3.2
unnamed: D5.2, SW4.2
unnamed: D6.2, SW5.2
unnamed: D7.2, SW6.2
unnamed: D8.2, SW7.2
unnamed: D9.2, SW8.2
unnamed: D10.2, SW9.2
unnamed: D11.2, SW10.2
unnamed: D12.2, SW11.2
unnamed: D13.2, SW12.2
unnamed: D14.2, SW13.2
unnamed: D15.2, SW14.2
unnamed: D16.2, SW15.2
unnamed: D17.2, SW16.2
unnamed: D18.2, SW17.2
unnamed: D19.2, SW18.2
unnamed: D20.2, SW19.2
unnamed: D21.2, SW20.2
unnamed: D22.2, SW21.2
unnamed: D23.2, SW22.2
unnamed: D24.2, SW23.2
unnamed: D25.2, SW24.2
unnamed: D26.2, SW25.2
unnamed: D27.2, SW26.2
unnamed: D28.2, SW27.2
unnamed: D29.2, SW28.2
unnamed: D30.2, SW29.2
unnamed: D31.2, SW30.2
unnamed: D32.2, SW31.2
unnamed: D33.2, SW32.2
unnamed: D34.2, SW33.2
unnamed: D35.2, SW34.2
unnamed: D36.2, SW35.2
unnamed: D37.2, SW36.2
unnamed: D38.2, SW37.2
unnamed: D39.2, SW38.2
unnamed: D40.2, SW39.2
unnamed: D41.2, SW40.2
unnamed: D42.2, SW41.2
unnamed: D43.2, SW42.2
unnamed: D44.2, SW43.2
unnamed: D45.2, SW44.2
unnamed: D46.2, SW45.2
unnamed: D47.2, SW46.2
unnamed: D48.2, SW47.2
unnamed: D49.2, SW48.2
unnamed: D50.2, SW49.2
unnamed: D51.2, SW50.2
unnamed: D52.2, SW51.2
unnamed: D53.2, SW52.2
unnamed: D54.2, SW53.S2
unnamed: D55.2, SW54.S2
unnamed: D56.2, SW55.S2
unnamed: D57.2, SW56.S2
unnamed: D60.2, L1.2, U6.1
unnamed: D61.1, IC2.18
unnamed: D62.1, IC2.16
unnamed: D63.1, IC2.14
unnamed: D64.1, IC2.12
unnamed: D65.1, IC2.10
unnamed: D66.2, D67.4
unnamed: D66.4, R29.1
unnamed: D67.2, D68.4
unnamed: D68.2, D69.4
unnamed: D69.2, D70.4
unnamed: D70.2, D71.4
unnamed: D71.2, D72.4
unnamed: D72.2, D73.4
unnamed: D73.2, D74.4
unnamed: D74.2, D75.4
unnamed: D75.2, D76.4
unnamed: D76.2, D77.4
unnamed: D77.2, D78.4
unnamed: D78.2, D79.4
unnamed: D79.2, D80.4
unnamed: D80.2, D81.4
unnamed: D81.2, D82.4
unnamed: D83.1, R30.1
unnamed: D83.2, D84.1
unnamed: D84.2, D85.2, SW57.2
unnamed: IC1.6, R14.2, R16.1
unnamed: IC1.8, R15.2, R16.2
unnamed: IC1.11, R15.1
unnamed: IC2.2, IC2.4, IC2.8, Q1.3, R27.1, RV1.3
unnamed: IC2.5, RV1.2
unnamed: IC2.6, IC2.7, RV1.1
unnamed: M1.4, U5.1
unnamed: M1.6, U5.3
unnamed: R2.2, U1.38
unnamed: R3.1, R8.2, SW53.B
unnamed: R4.1, R9.2, SW54.B
unnamed: R5.1, R10.2, SW55.B
unnamed: R6.1, R11.2, SW56.B
unnamed: R7.1, R12.2, SW53.A, SW54.A, SW55.A, SW56.A
unnamed: R17.1, R18.1, U3.3
unnamed: R20.1, U4.7
unnamed: R21.1, U4.6
unnamed: R22.1, U4.2
unnamed: R24.1, U5.2
unnamed: R25.1, R26.2, U6.3
OUT_PIN: J7.3, R31.2
PD4: C11.1, R12.1, U1.25
PE6: R19.2, U1.1, U3.1
PF4: IC1.3, R13.2, R14.1, U1.39, U3.2
RESET: JP1.1, R1.2, U1.13
ROW1: SW1.1, SW5.1, SW9.1, SW13.1, SW17.1, SW21.1, SW25.1, SW29.1, SW33.1, SW37.1, SW41.1, SW45.1, SW49.1, SW53.S1, U1.30
ROW2: SW2.1, SW6.1, SW10.1, SW14.1, SW18.1, SW22.1, SW26.1, SW30.1, SW34.1, SW38.1, SW42.1, SW46.1, SW50.1, SW54.S1, U1.28
ROW3: SW3.1, SW7.1, SW11.1, SW15.1, SW19.1, SW23.1, SW27.1, SW31.1, SW35.1, SW39.1, SW43.1, SW47.1, SW51.1, SW55.S1, U1.27
ROW4: SW4.1, SW8.1, SW12.1, SW16.1, SW20.1, SW24.1, SW28.1, SW32.1, SW36.1, SW40.1, SW44.1, SW48.1, SW52.1, SW56.S1, U1.26
SENSE_PIN: C33.2, J7.4, R30.2

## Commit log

2018-09-11 first upload
    [1050170001.stp, DAC.sch, OTTO-power.kicad_pcb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]
2018-09-13 cleaned schematics
    [OTTO-power.sch, OTTOdac.sch]
2018-09-14 new board, still needs gnd to be routed
    [OTTOdac.kicad_pcb]
2018-09-14 new board, need to route the DC connector (and make a protection circuit between it and the usb)
    [OTTO-power.kicad_pcb, OTTO-power.sch]
2018-09-14 added a dxf file to help align the boards and connectors
    [OTTO_align.dxf]
2018-09-14 routed ground and added mounting holes
    [OTTOdac.kicad_pcb]
2018-09-15 started working on the mainboard
    [OTTO-main.kicad_pcb, OTTO-main.sch, OTTO-power.kicad_pcb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]
2018-09-16 some progress on the main board design
    [OTTO-main.kicad_pcb, OTTO-main.sch, OTTO_align.dxf]
2018-09-19 new powerboard circuit
    [OTTO-main.sch, OTTO-power.kicad_pcb, OTTO-power.sch]
2018-09-20 some advancement on the power board layout
    [OTTO-power.kicad_pcb, OTTO-power.sch, OTTO_align.dxf]
2018-09-24 some rework on the routing
    [OTTO-power.kicad_pcb]
2018-09-24 solved some issues with the libraries
    [OTTOdac.sch]
